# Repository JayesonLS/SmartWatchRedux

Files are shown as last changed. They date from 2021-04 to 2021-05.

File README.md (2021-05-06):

SmartWatch Redux
================

Modern replacements for the DS1216 SmartWatch variants.

SmartWatchRedux-E
-----------------

Status: Version 1.0 built, tested and working. Version 1.1 (minor changes) untested.

A replacement for the DS1216-E. This SmartWatch is for use on a BIOS
or exapansion ROM socket. It is typically placed in between an existing
BIOS ROM and its socket.

This clock is compatible with Y2K and current dates when used with this
software availalbe here: https://www.dropbox.com/s/kctqpwzjxgymfz9/smwy2k.zip?dl=0
or here: 
ftp://ftp.oldskool.org/pub/tvdog/tandy1000/utilities/smwy2k.zip

ATD-20-Redux
------------

Status: Untested. 

A replacement for the ATD-20 clock. This is used in ATD exansion boards 
for the Tandy 1000 computers such as the T512CLK-A1. It is believed that
the ATD-20 is, or is compatible with, the DS1216-B/C SmartWatch. However, 
the ATD-20 does not allow, nor require, a BIOS rom to be fitted to the 
top of the module.

A DS1216-C has been tested in a T512CLK-A1 and works fine. If purchasing
an original DS1216-C today, it may be necessary to retrofit a battery replacement.
Google "DS1216 battery replacement". 

Software for the ATD-20 (or DS1216-C) located in a T512CLK-A1 is available
from here: http://www.minuszerodegrees.net/rtc/rtc.htm . It seems to work
correctly with current dates.

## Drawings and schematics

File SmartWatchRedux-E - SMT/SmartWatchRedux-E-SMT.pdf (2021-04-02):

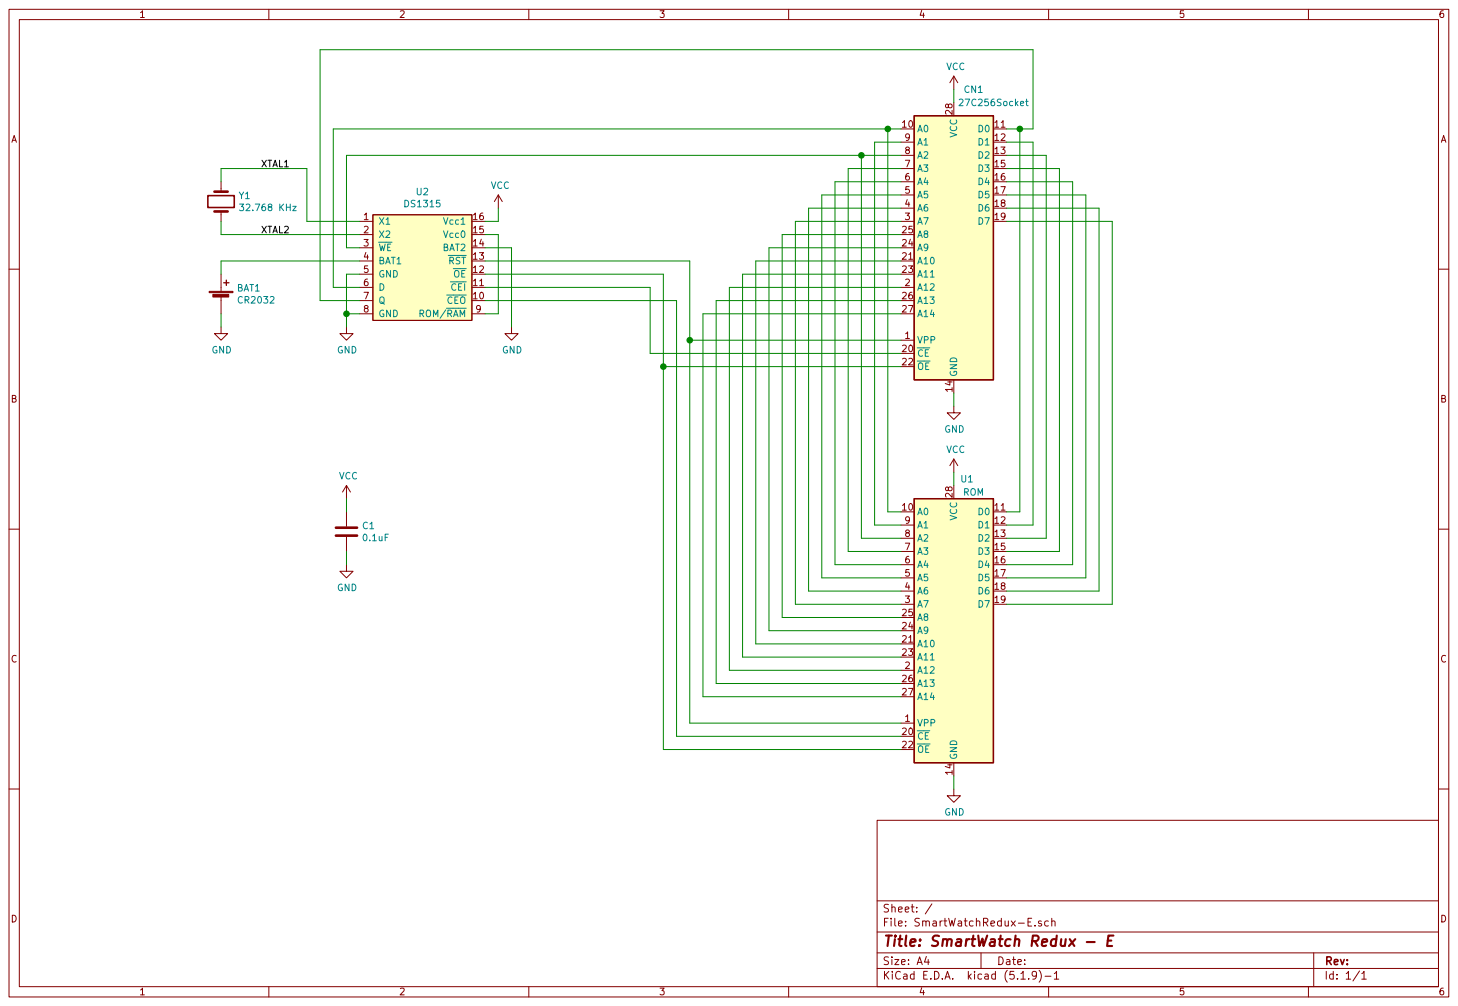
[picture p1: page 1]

File: SmartWatchRedux-E.sch Sheet: /
Id: 1/1 Title: SmartWatch Redux - E

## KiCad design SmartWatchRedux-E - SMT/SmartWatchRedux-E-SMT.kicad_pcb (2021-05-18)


Board: 2 copper layers, 24.7 x 69.9 mm, 6 parts (0 on the bottom side), 33 nets.

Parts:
BAT1: CR2032; BatteryHolder_Keystone_1060_1x2032
C1: 0.1uF; C_1206_3216Metric
CN1: 27C256Socket; DIP-28_W15.24mm
U1: ROM; DIP-28_W15.24mm_Socket
U2: DS1315; DIP-16_W7.62mm
Y1: 32.768 KHz; Crystal_SMD_3215-2Pin_3.2x1.5mm

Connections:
/XTAL1: U2.1, Y1.1
/XTAL2: U2.2, Y1.2
GND: BAT1.2, C1.2, CN1.14, U1.14, U2.5, U2.8, U2.14
unnamed: BAT1.1, U2.4
unnamed: CN1.1, U1.1, U2.13
unnamed: CN1.2, U1.2
unnamed: CN1.3, U1.3
unnamed: CN1.4, U1.4
unnamed: CN1.5, U1.5
unnamed: CN1.6, U1.6
unnamed: CN1.7, U1.7
unnamed: CN1.8, U1.8, U2.3
unnamed: CN1.9, U1.9
unnamed: CN1.10, U1.10, U2.6
unnamed: CN1.11, U1.11, U2.7
unnamed: CN1.12, U1.12
unnamed: CN1.13, U1.13
unnamed: CN1.15, U1.15
unnamed: CN1.16, U1.16
unnamed: CN1.17, U1.17
unnamed: CN1.18, U1.18
unnamed: CN1.19, U1.19
unnamed: CN1.20, U2.11
unnamed: CN1.21, U1.21
unnamed: CN1.22, U1.22, U2.12
unnamed: CN1.23, U1.23
unnamed: CN1.24, U1.24
unnamed: CN1.25, U1.25
unnamed: CN1.26, U1.26
unnamed: CN1.27, U1.27
unnamed: U1.20, U2.10
unnamed: U2.9, U2.15
VCC: C1.1, CN1.28, U1.28, U2.16

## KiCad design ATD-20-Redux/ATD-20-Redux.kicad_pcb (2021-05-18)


Board: 2 copper layers, 24.3 x 64.1 mm, 5 parts (0 on the bottom side), 9 nets.

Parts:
BAT1: CR2032; BatteryHolder_Keystone_1060_1x2032
C1: 0.1uF; C_Disc_D4.3mm_W1.9mm_P5.00mm
J1: RTC Pins; DIP-28_W15.24mm_Socket
U1: DS1315; DIP-16_W7.62mm
Y1: 32.768 KHz; Crystal_C38-LF_D3.0mm_L8.0mm_Horizontal

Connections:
/D0: J1.11, U1.6, U1.7
/XTAL1: U1.1, Y1.1
/XTAL2: U1.2, Y1.2
/~CS_RTC: J1.20, U1.11
/~IOR: J1.22, U1.12
/~IOW: J1.27, U1.3
GND: BAT1.2, C1.2, J1.14, U1.5, U1.8, U1.9, U1.14
unnamed: BAT1.1, U1.4
VCC: C1.1, J1.28, U1.13, U1.16

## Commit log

2021-04-02 Strip non-SmartWatch projects from a copy of TandyCircuitsAndLogic in order to place SmartWatch projects into their own repository.
    [CoCoProtoBoard-B_Cu.gbl, CoCoProtoBoard-B_Mask.gbs, CoCoProtoBoard-B_SilkS.gbo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]
2021-04-02 Minor tweakes to board, add -E to name.
    [SmartWatchRedux-E.kicad_pcb, SmartWatchRedux-E.sch]
2021-04-02 SmartWatchRedux-E: Fix version number.
    [SmartWatchRedux-E.kicad_pcb]
2021-04-02 SmartWatchRedux-E: Add gerbers
    [SmartWatchRedux-E-B_Cu.gbl, SmartWatchRedux-E-B_Mask.gbs, SmartWatchRedux-E-B_SilkS.gbo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]
2021-04-03 Flipped layout of ATD-20 Redux so battery was at other end. This is to make it easier to change the battery. The battery holder is also slightly off-center to allow battery holder pin to fit between 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
    [ATD-20-Redux.kicad_pcb]
2021-04-04 Update SmartWatchRedux-E gerbers.
    [SmartWatchRedux-E-B_Mask.gbs, SmartWatchRedux-E-B_SilkS.gbo, SmartWatchRedux-E-Edge_Cuts.gm1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]
2021-04-04 Add files missing from previous commit.
    [SmartWatchRedux-E-B_Cu.gbl, SmartWatchRedux-E.drl]
2021-04-04 Add initial pass at assembly board.
    [AssemblyBoard.kicad_pcb, AssemblyBoard.sch]
2021-04-04 Add gerbers for AssembyBoard.
    [AssemblyBoard-B_Cu.gbl, AssemblyBoard-B_Mask.gbs, AssemblyBoard-B_SilkS.gbo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]
2021-04-04 Add gerbets for ATD-20-Redux.
    [ATD-20-Redux-B_Cu.gbl, ATD-20-Redux-B_Mask.gbs, ATD-20-Redux-B_SilkS.gbo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]
2021-05-06 Gerber plots for AssemblyBoard and SmartWatchRedux. Minor board shape change on SmartWatchRedux.
    [AssemblyBoard-B_Cu.gbl, AssemblyBoard-B_Mask.gbs, AssemblyBoard-B_SilkS.gbo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]
2021-05-06 Change battery holder on ATD-20-Redux to something that is not as tall. This is to increase the distance between the battery and the adjacent board.
    [ATD-20-Redux.kicad_pcb]
2021-05-06 Minor tweaks to ATD-20-Redux.
    [ATD-20-Redux.kicad_pcb]
2021-05-06 Gerbers for ATD-20-Redux.
    [ATD-20-Redux-B_Cu.gbl, ATD-20-Redux-B_Mask.gbs, ATD-20-Redux-B_SilkS.gbo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]
2021-05-18 ATD-20-Redux - Add small notch to indicate top of board.
    [ATD-20-Redux.kicad_pcb]
2021-05-18 Create SmartWatchRedux-E-SMT: SMT version of SmartWatchRedux-E. Switches both the crystal and the battery holder to SMT. The bypass cap was already SMT.
    [SmartWatchRedux-E-SMT-B_Cu.gbl, SmartWatchRedux-E-SMT-B_Mask.gbs, SmartWatchRedux-E-SMT-B_SilkS.gbo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]
2023-11-04 Adding SmartWatchTest which is dated from 2021-07-14. Not sure what kind of state this is in.
    [SmartWatchTest.kicad_pcb, SmartWatchTest.sch]

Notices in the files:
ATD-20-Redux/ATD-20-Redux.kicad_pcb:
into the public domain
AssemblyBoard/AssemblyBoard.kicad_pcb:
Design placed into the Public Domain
